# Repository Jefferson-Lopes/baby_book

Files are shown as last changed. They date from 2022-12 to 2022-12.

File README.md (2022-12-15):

# Baby Engineer: Logic Gates

The book "Baby Engineer: Logic Gates" is designed to teach logic gates to kids and teenagers. It is especially appealing to kids with autism since it uses visual and auditory signs to keep their interest.

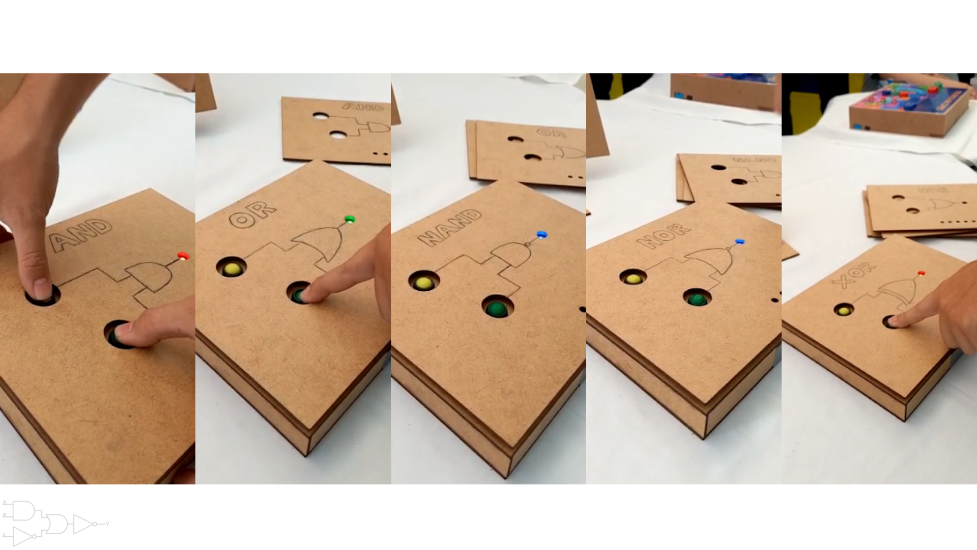
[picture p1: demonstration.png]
demo


# Development

## Circuit

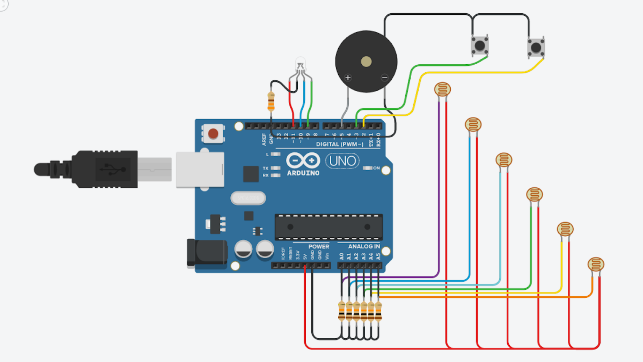
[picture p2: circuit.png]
circuit


## 3D design

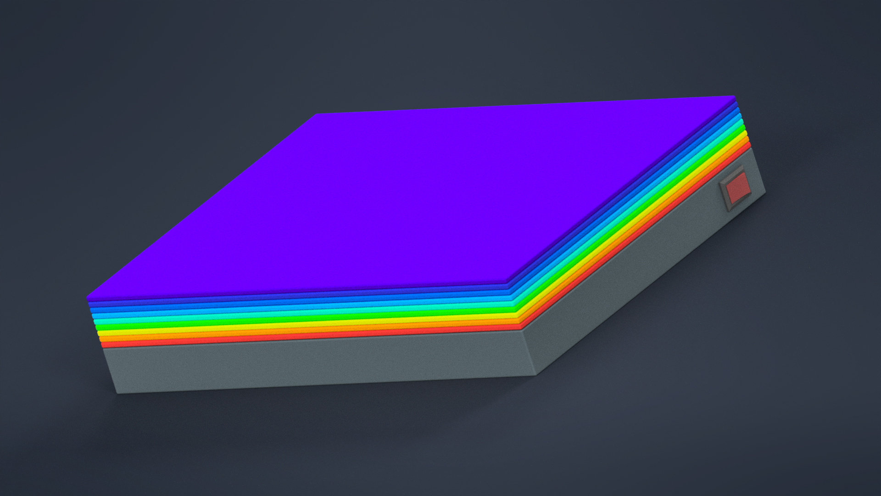
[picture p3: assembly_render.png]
render

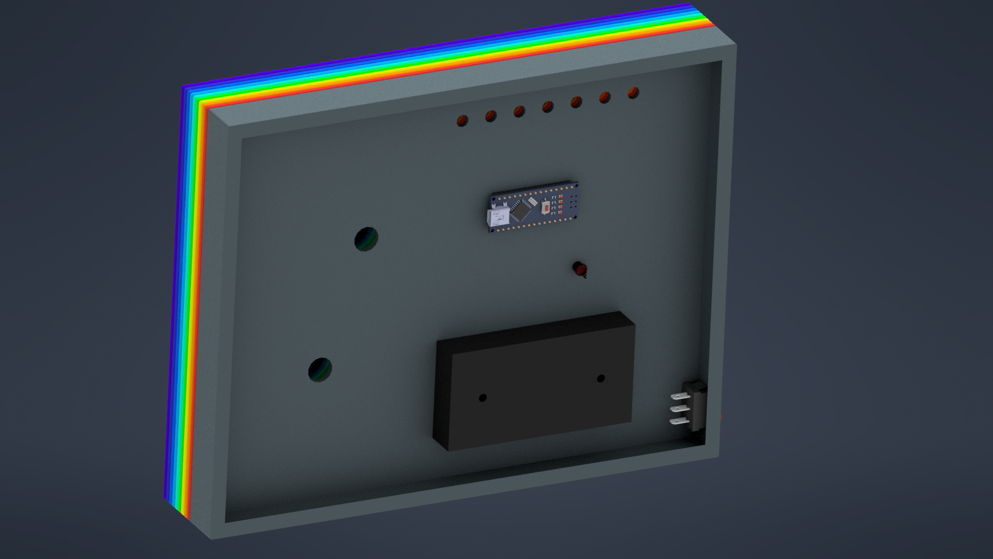
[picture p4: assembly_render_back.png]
render back


## Laser cut

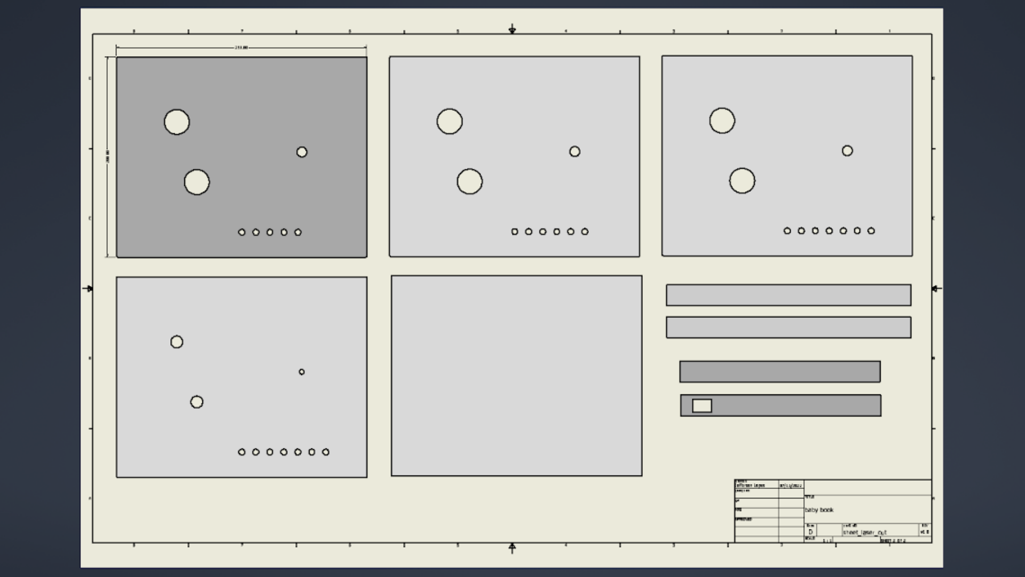
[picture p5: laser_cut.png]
laser cut


# Delivery day

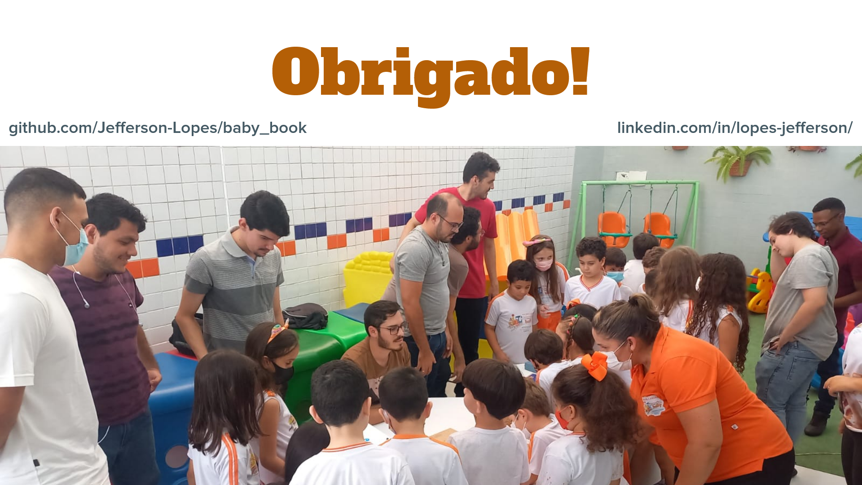
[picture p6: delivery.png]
delivery day


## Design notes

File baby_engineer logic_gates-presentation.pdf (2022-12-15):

# baby engineer:

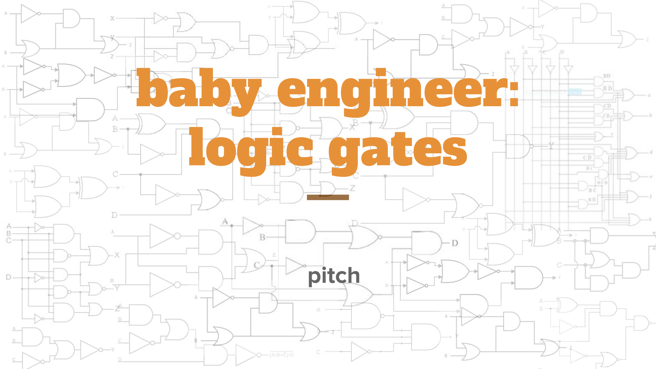
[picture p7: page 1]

# logic gates

# pitch

# Resolução de problemas

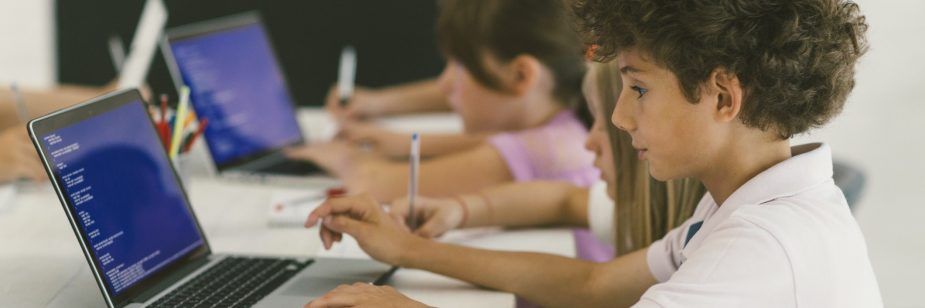
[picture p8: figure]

# Soluções existentes e limitações

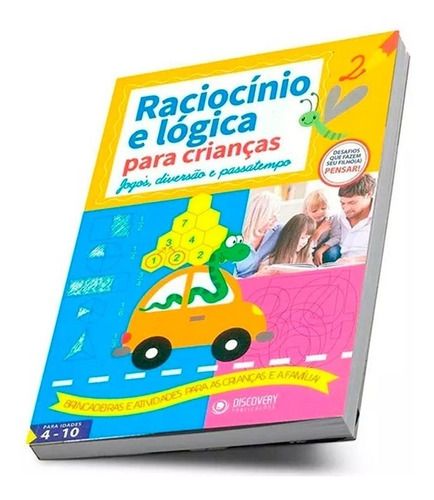
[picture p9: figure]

### - sem inovação de ensino

### - falta de técnicas de inclusão

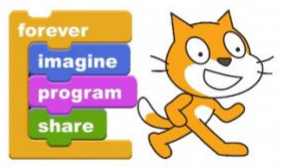
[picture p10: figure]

### - falta de experiência imersiva com tato

### - maior custo para implementação em escolas

# Solução proposta

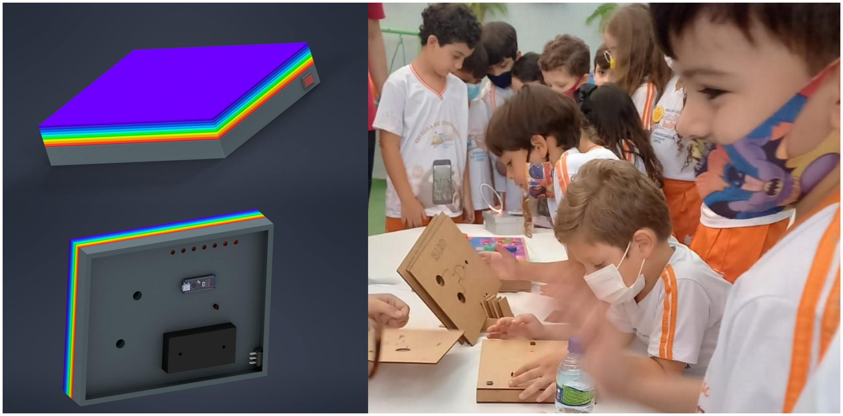
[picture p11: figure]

# Diferencial

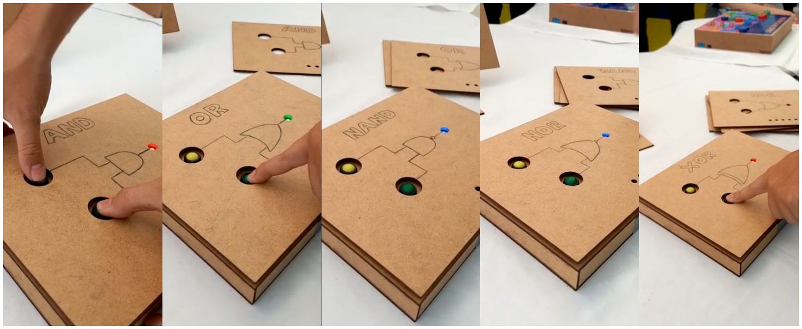
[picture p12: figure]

# Público alvo

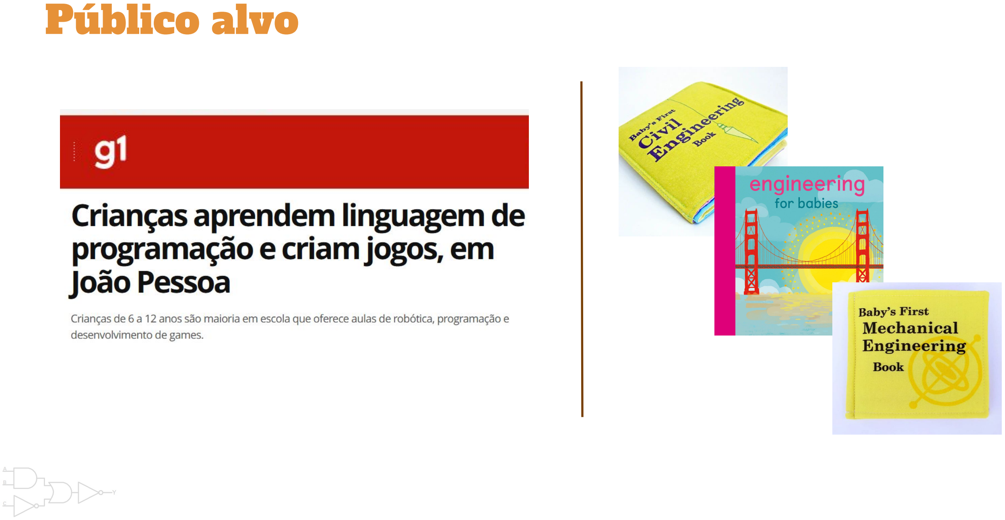
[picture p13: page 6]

# Custos

custo de desenvolvimento

descrição | quant. | valor unitário | custo
MDF / corte a laser | 1 | R$ 80,00 | R$ 80,00
Arduino Uno | 1 | R$ 60,00 | R$ 60,00
Suporte para pilhas | 1 | R$ 7,50 | R$ 7,50
Buzzer | 1 | R$ 2,50 | R$ 2,50
chave on off | 1 | R$ 2,50 | R$ 2,50
push button | 2 | R$ 4,90 | R$ 9,80
fios | 2 | R$ 1,90 | R$ 3,80
LDR | 7 | R$ 0,50 | R$ 3,50
tempo de desenvolvimento | 20 | R$ 15,00 | R$ 300,00
custo total de desenvolvimento | R$ 469,60

custo de produção

descrição | quant. | valor unitário | custo
MDF / corte a laser | 1 | R$ 50,00 | R$ 50,00
MCU Atmega328p | 1 | R$ 15,00 | R$ 15,00
PCB na JLCPCB | 1 | R$ 5,00 | R$ 5,00
bateria 9V | 1 | R$ 12,00 | R$ 12,00
conector jack bateria | 1 | R$ 2,50 | R$ 2,50
LED RGB difuso | 1 | R$ 0,50 | R$ 0,50
Buzzer | 1 | R$ 2,50 | R$ 2,50
LDR | 7 | R$ 0,50 | R$ 3,50
botão fliperama | 2 | R$ 10,00 | R$ 20,00
chave on off | 1 | R$ 2,50 | R$ 2,50
tempo de montagem | 4 | R$ 15,00 | R$ 60,00
custo total por unidade | R$ 173,50

# ROI (retorno sobre investimento)

venda à R$250,00

quant. | custo | entrada | balanço
0 | R$ 469,60 | R$ 0,00 | -R$ 469,60
1 | R$ 643,10 | R$ 250,00 | -R$ 393,10
2 | R$ 816,60 | R$ 500,00 | -R$ 316,60
3 | R$ 990,10 | R$ 750,00 | -R$ 240,10
4 | R$ 1.163,60 | R$ 1.000,00 | -R$ 163,60
5 | R$ 1.337,10 | R$ 1.250,00 | -R$ 87,10
6 | R$ 1.510,60 | R$ 1.500,00 | -R$ 10,60
7 | R$ 1.684,10 | R$ 1.750,00 | R$ 65,90
8 | R$ 1.857,60 | R$ 2.000,00 | R$ 142,40
9 | R$ 2.031,10 | R$ 2.250,00 | R$ 218,90
10 | R$ 2.204,60 | R$ 2.500,00 | R$ 295,40

venda à R$300,00

quant. | custo | entrada | balanço
0 | R$ 469,60 | R$ 0,00 | -R$ 469,60
1 | R$ 643,10 | R$ 300,00 | -R$ 343,10
2 | R$ 816,60 | R$ 600,00 | -R$ 216,60
3 | R$ 990,10 | R$ 900,00 | -R$ 90,10
4 | R$ 1.163,60 | R$ 1.200,00 | R$ 36,40
5 | R$ 1.337,10 | R$ 1.500,00 | R$ 162,90
6 | R$ 1.510,60 | R$ 1.800,00 | R$ 289,40
7 | R$ 1.684,10 | R$ 2.100,00 | R$ 415,90
8 | R$ 1.857,60 | R$ 2.400,00 | R$ 542,40
9 | R$ 2.031,10 | R$ 2.700,00 | R$ 668,90
10 | R$ 2.204,60 | R$ 3.000,00 | R$ 795,40

# ROI (retorno sobre investimento)

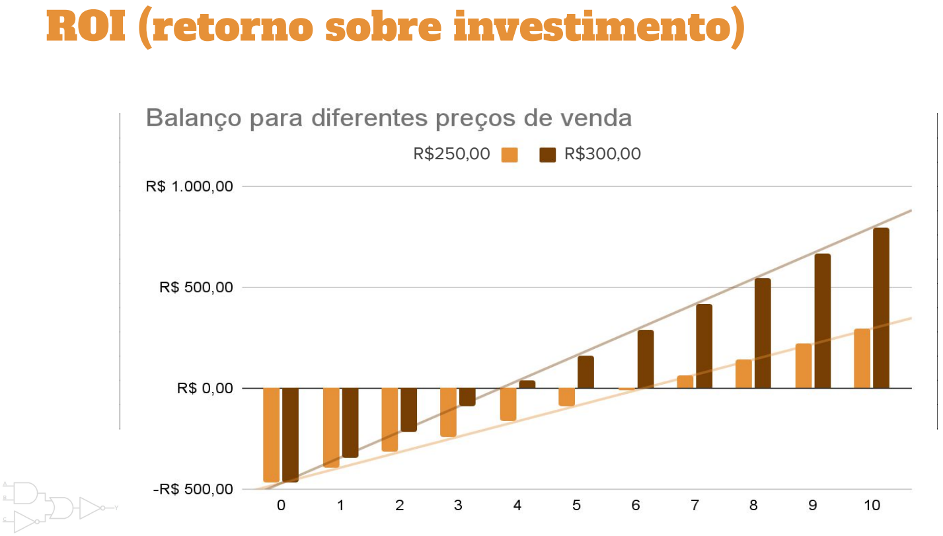
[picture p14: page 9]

venda à R$250,00

quant. | custo | entrada | balanço
0 | R$ 469,60 | R$ 0,00 | -R$ 469,60
1 | R$ 643,10 | R$ 250,00 | -R$ 393,10
2 | R$ 816,60 | R$ 500,00 | -R$ 316,60
3 | R$ 990,10 | R$ 750,00 | -R$ 240,10
4 | R$ 1.163,60 | R$ 1.000,00 | -R$ 163,60
5 | R$ 1.337,10 | R$ 1.250,00 | -R$ 87,10
6 | R$ 1.510,60 | R$ 1.500,00 | -R$ 10,60
7 | R$ 1.684,10 | R$ 1.750,00 | R$ 65,90
8 | R$ 1.857,60 | R$ 2.000,00 | R$ 142,40
9 | R$ 2.031,10 | R$ 2.250,00 | R$ 218,90
10 | R$ 2.204,60 | R$ 2.500,00 | R$ 295,40

venda à R$300,00

quant. | custo | entrada | balanço
0 | R$ 469,60 | R$ 0,00 | -R$ 469,60
1 | R$ 643,10 | R$ 300,00 | -R$ 343,10
2 | R$ 816,60 | R$ 600,00 | -R$ 216,60
3 | R$ 990,10 | R$ 900,00 | -R$ 90,10
4 | R$ 1.163,60 | R$ 1.200,00 | R$ 36,40
5 | R$ 1.337,10 | R$ 1.500,00 | R$ 162,90
6 | R$ 1.510,60 | R$ 1.800,00 | R$ 289,40
7 | R$ 1.684,10 | R$ 2.100,00 | R$ 415,90
8 | R$ 1.857,60 | R$ 2.400,00 | R$ 542,40
9 | R$ 2.031,10 | R$ 2.700,00 | R$ 668,90
10 | R$ 2.204,60 | R$ 3.000,00 | R$ 795,40
R$250,00 | R$300,00

# Obrigado!

github.com/Jefferson-Lopes/baby_book | linkedin.com/in/lopes-jefferson/

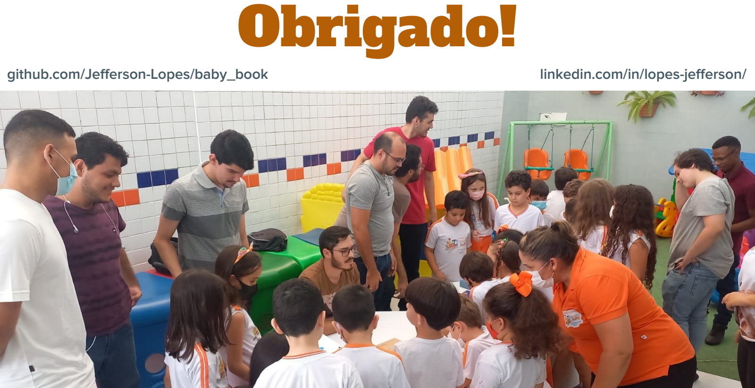
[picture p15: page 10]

# baby engineer:

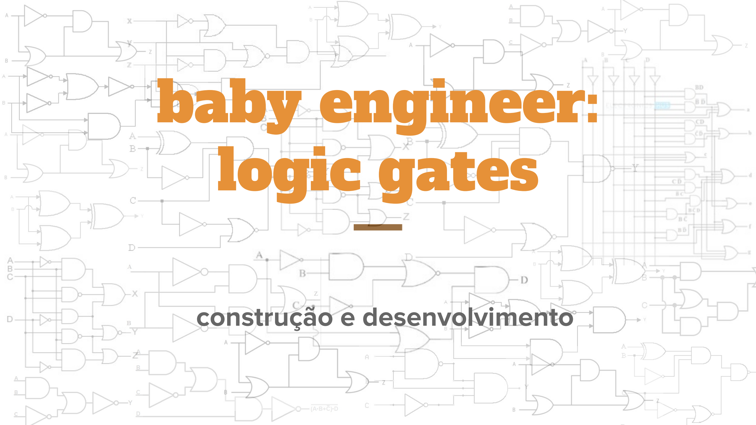
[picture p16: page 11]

# logic gates

# construção e desenvolvimento

# Layout do brinquedo

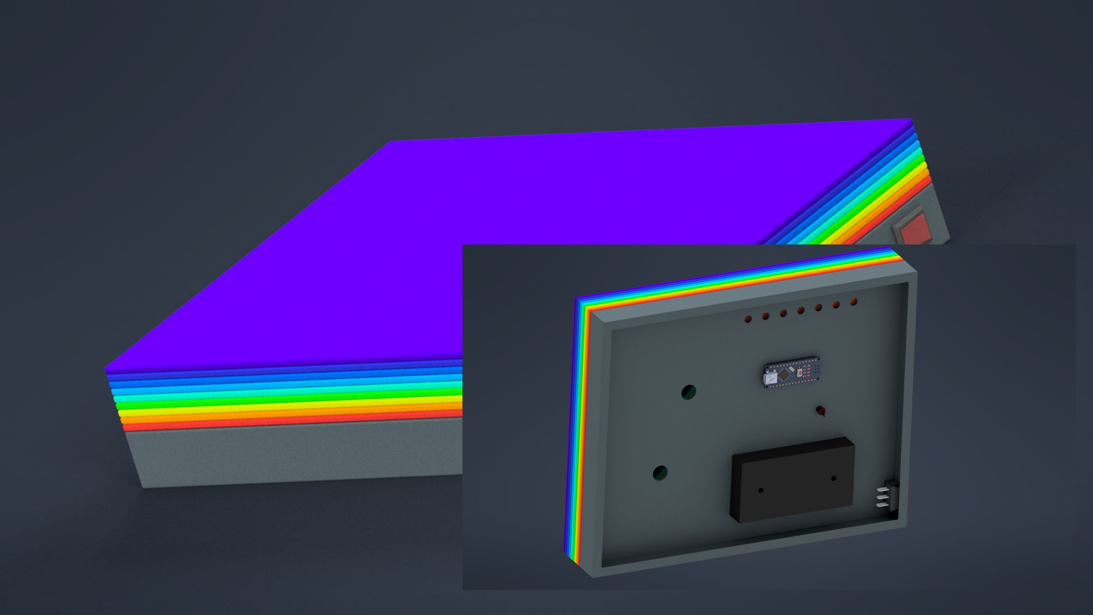
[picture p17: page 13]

# Construção em MDF / corte a laser

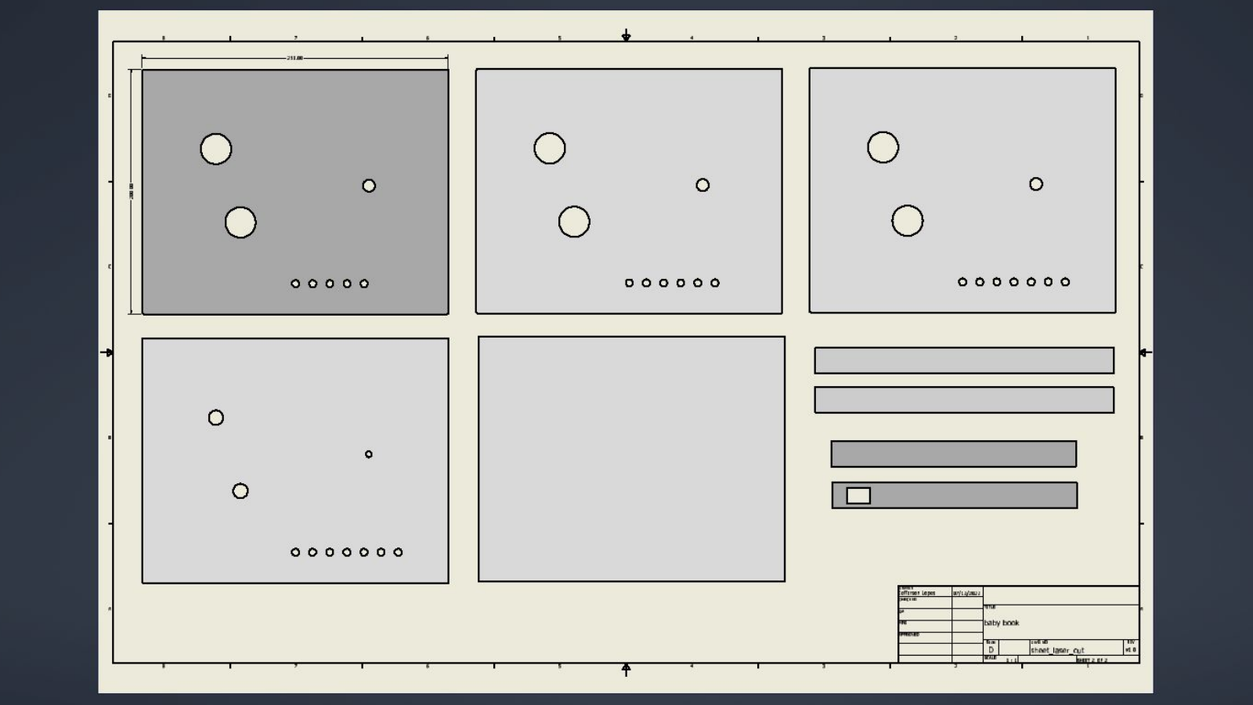
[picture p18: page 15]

# Circuito

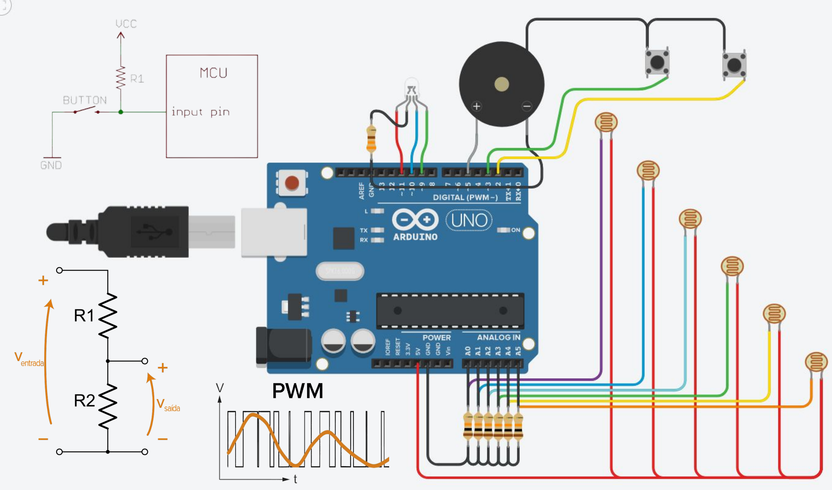
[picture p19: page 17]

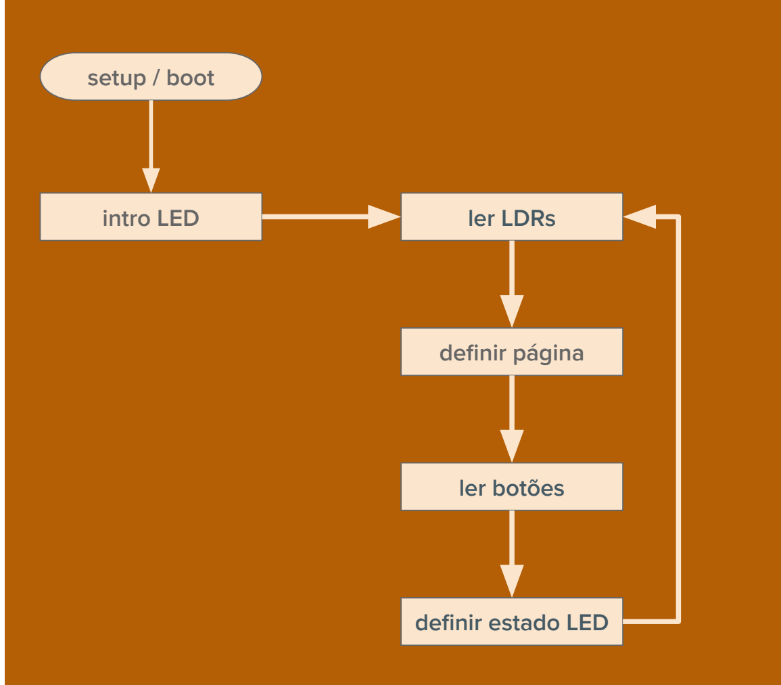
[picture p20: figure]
setup / boot; intro LED; ler LDRs; definir página; ler botões; definir estado LED

# Código

# Diagrama de blocos

# Funcionamento

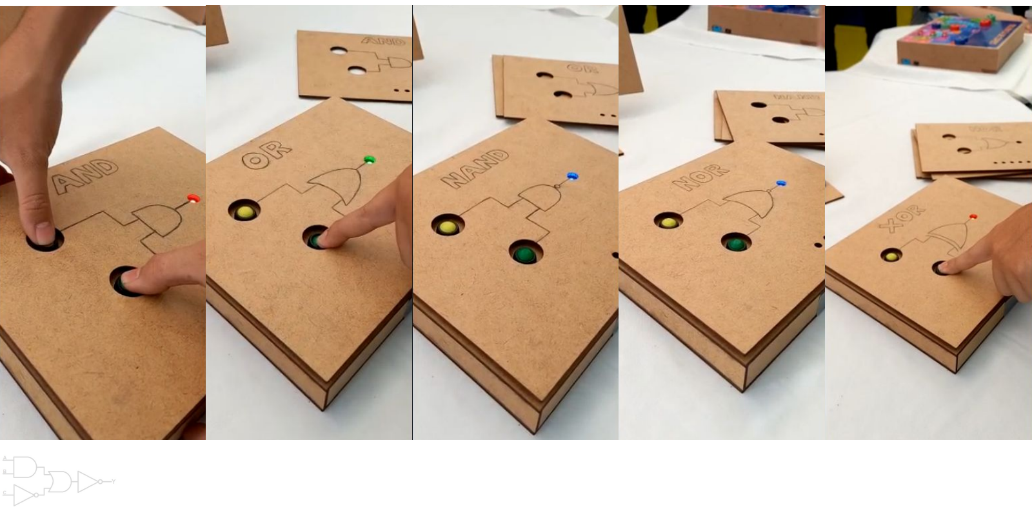
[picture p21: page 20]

# Obrigado!

github.com/Jefferson-Lopes/baby_book | linkedin.com/in/lopes-jefferson/

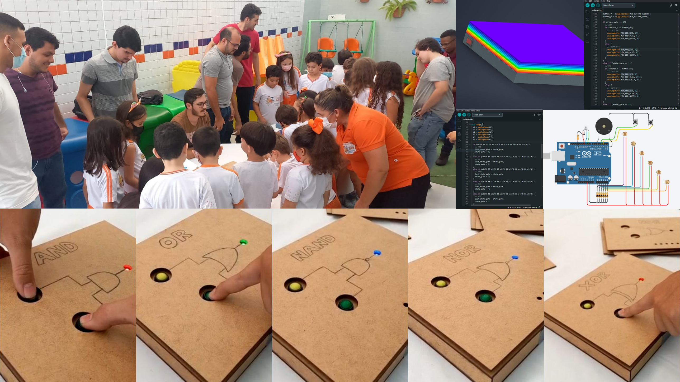
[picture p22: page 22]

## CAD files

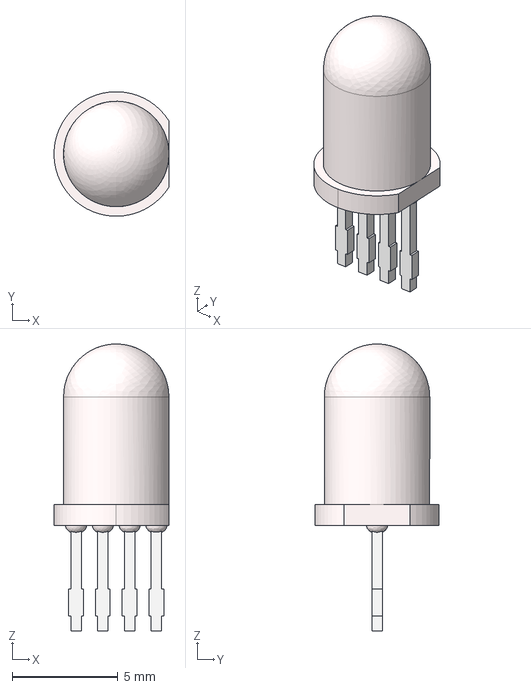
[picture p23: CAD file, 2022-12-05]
CAD/imported/LED T-1, dia 5mm, RGB, h2mm.stp
5.45 x 5.90 x 13.6 mm

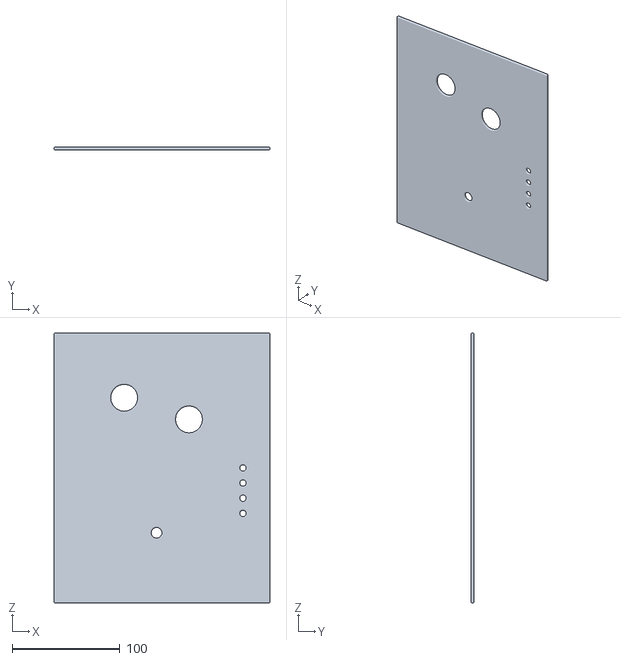
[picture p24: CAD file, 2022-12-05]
CAD/impressão/pages_05_nand.stl
200.0 x 3.00 x 250.0

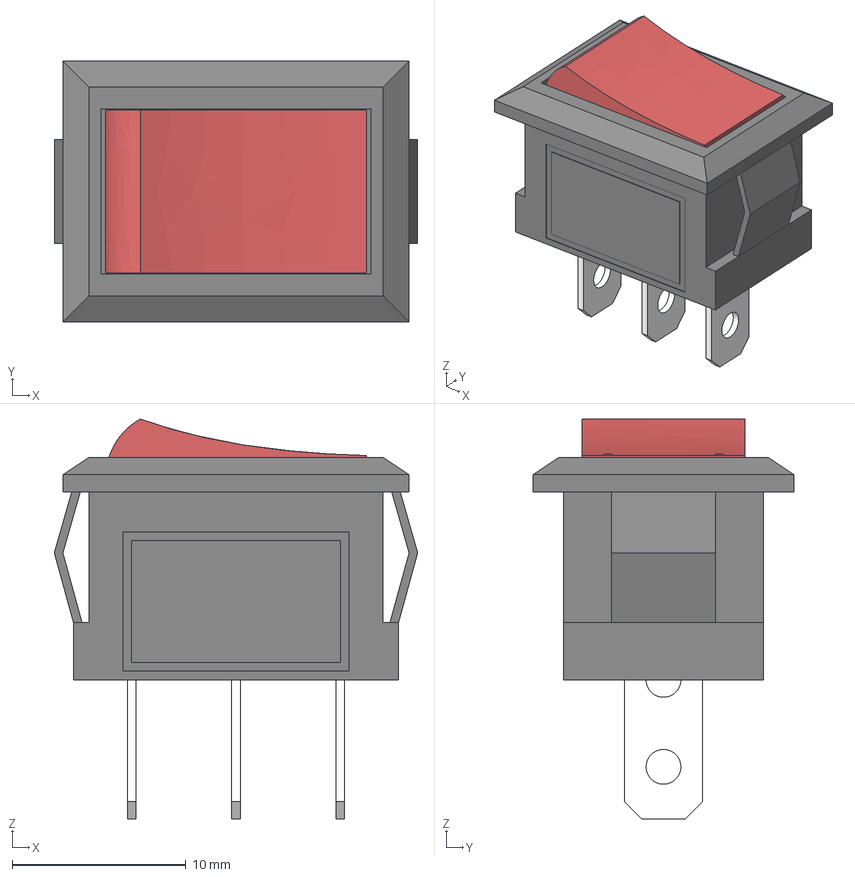
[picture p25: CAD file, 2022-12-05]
CAD/imported/pwr_switch.step
20.9 x 15.0 x 23.0 mm

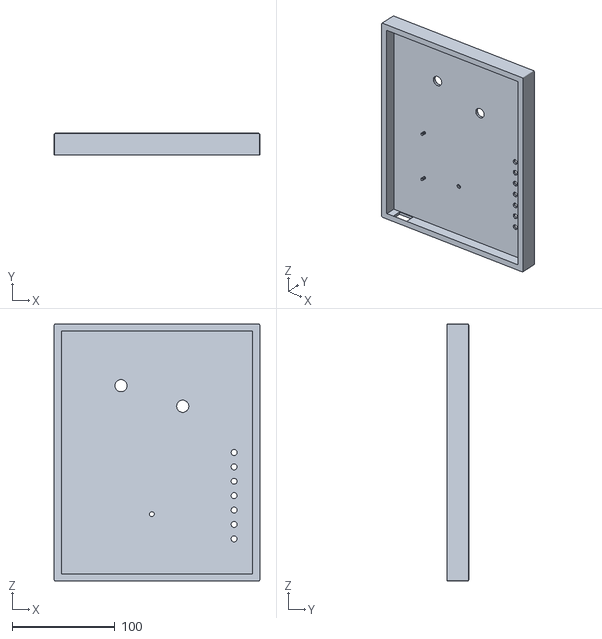
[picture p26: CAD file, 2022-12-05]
CAD/impressão/back.stl
200.0 x 21.0 x 250.0

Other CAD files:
CAD/drawings/laser_cut_Sheet_1.dxf
CAD/drawings/laser_cut.dwg
CAD/impressão/pages_03_and.stl
CAD/drawings/laser_cut_Sheet_2.dxf
CAD/impressão/pages_02_not.stl
CAD/impressão/pages_07_xor.stl
CAD/impressão/back_cover.stl
CAD/impressão/pages_06_nor.stl
CAD/impressão/pages_08_extra.stl
CAD/impressão/pages_00_cover.stl
CAD/impressão/pages_04_or.stl
CAD/impressão/pages_01_wire.stl
CAD/back.ipt
CAD/back_cover.ipt
CAD/back_side_botton.ipt
CAD/back_side_left.ipt
CAD/back_side_right.ipt
CAD/back_side_top.ipt
CAD/back_top.ipt
CAD/battery_case.ipt
CAD/lines_base.ipt
CAD/pages_00_cover.ipt
CAD/pages_01_wire.ipt
CAD/pages_02_not.ipt
CAD/pages_03_and.ipt
CAD/pages_04_or.ipt
CAD/pages_05_nand.ipt
CAD/pages_06_nor.ipt
CAD/pages_07_xor.ipt
CAD/pages_08_extra.ipt

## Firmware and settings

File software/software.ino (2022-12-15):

/**
 * @file software.ino
 * @author Jefferson Lopes (jefferson.lopes@ee.ufcg.edu.br)
 * @brief the book "Baby Engineer: Logic Gates" is designed to teach logic gates 
 *        to kids and teenagers. It is especially appealing to kids with autism 
 *        since it uses visual and auditory signs to keep their interest.
 * @version 0.1
 * @date 2022-12-15
 * 
 * @copyright Copyright (c) 2022
 * 
 */

// pinout
#define PIN_PIEZO 3
#define PIN_LED_RED 11
#define PIN_LED_BLUE 10
#define PIN_LED_GREEN 9
#define PIN_BUTTON_GREEN 4
#define PIN_BUTTON_YELLOW 2

// configs
#define TH 100 // THRESHOLD
#define INTRO_TIME 500 // intro delay time

// states
typedef enum {
    INIT,
    AND,
    OR,
    NAND,
    NOR,
    XOR,
    LATCH
} state_t;

// global vars
bool button_Y, button_G;
state_t state_gate = INIT;
state_t last_state_gate = INIT;
uint16_t a0, a1, a2, a3, a4, a5;

void setup(){
    pinMode(PIN_PIEZO, OUTPUT);
    pinMode(PIN_LED_RED, OUTPUT);
    pinMode(PIN_LED_BLUE, OUTPUT);
    pinMode(PIN_LED_GREEN, OUTPUT);
    pinMode(PIN_BUTTON_GREEN, INPUT_PULLUP);
    pinMode(PIN_BUTTON_YELLOW, INPUT_PULLUP);

    // init and config serial monitor
    Serial.begin(9600);

    // initial beep
    analogWrite(PIN_PIEZO, 125); delay(100);
    analogWrite(PIN_PIEZO, 0);   delay(100);
    analogWrite(PIN_PIEZO, 125); delay(100);
    analogWrite(PIN_PIEZO, 0);

    // RGB intro
    analogWrite(PIN_LED_RED, 255); delay(INTRO_TIME);
    analogWrite(PIN_LED_BLUE, 255); delay(INTRO_TIME);
    analogWrite(PIN_LED_GREEN, 255); delay(INTRO_TIME);
    analogWrite(PIN_LED_RED, 0); delay(INTRO_TIME);
    analogWrite(PIN_LED_BLUE, 0); delay(INTRO_TIME);
    analogWrite(PIN_LED_GREEN, 0); delay(INTRO_TIME);
}

void loop(){
    define_state();

    update_logic();

    delay(10);
}

void define_state(void){
    a0 = analogRead(A0);
    a1 = analogRead(A1);
    a2 = analogRead(A2);
    a3 = analogRead(A3);
    a4 = analogRead(A4);
    a5 = analogRead(A5);

    if (a0 > TH && a1 < TH && a2 < TH && a3 < TH && a4 < TH && a5 < TH){
        // AND
        last_state_gate = state_gate;
        state_gate = AND;
    }
    else if (a0 > TH && a1 > TH && a2 < TH && a3 < TH && a4 < TH && a5 < TH){
        // OR
        last_state_gate = state_gate;
        state_gate = OR;
    }
    else if (a0 > TH && a1 > TH && a2 > TH && a3 < TH && a4 < TH && a5 < TH){
        // NAND
        last_state_gate = state_gate;
        state_gate = NAND;
    }
    else if (a0 > TH && a1 > TH && a2 > TH && a3 > TH && a4 < TH && a5 < TH){
        // NOR
        last_state_gate = state_gate;
        state_gate = NOR;
    }
    else if (a0 > TH && a1 > TH && a2 > TH && a3 > TH && a4 > TH && a5 < TH){
        // XOR
        last_state_gate = state_gate;
        state_gate = XOR;
    }
    else if (a0 > TH && a1 > TH && a2 > TH && a3 > TH && a4 > TH && a5 > TH){
        // LATCH
        last_state_gate = state_gate;
        state_gate = LATCH;
    }

    if (last_state_gate != state_gate){
        // turn off LED
        analogWrite(PIN_LED_RED, 0);
        analogWrite(PIN_LED_BLUE, 0);
        analogWrite(PIN_LED_GREEN, 0);

        // debug message
        Serial.print("New state: ");
        Serial.println(state_gate);

        delay(10);
    }
}

void update_logic(){
    button_Y = !digitalRead(PIN_BUTTON_YELLOW); // inverted logic
    button_G = !digitalRead(PIN_BUTTON_GREEN);  // inverted logic

    if (state_gate == AND){
        // AND
        if (button_Y & button_G){
            // turn on
            analogWrite(PIN_LED_RED, 255);
            analogWrite(PIN_LED_BLUE, 0);
            analogWrite(PIN_LED_GREEN, 0);
        }
        else{
            // turn off
            analogWrite(PIN_LED_RED, 0);
            analogWrite(PIN_LED_BLUE, 0);
            analogWrite(PIN_LED_GREEN, 0);
        }
    }
    else if (state_gate == OR){
        // OR
        if (button_Y | button_G){
            // turn on
            analogWrite(PIN_LED_RED, 0);
            analogWrite(PIN_LED_BLUE, 255);
            analogWrite(PIN_LED_GREEN, 0);
        }
        else{
            // turn off
            analogWrite(PIN_LED_RED, 0);
            analogWrite(PIN_LED_BLUE, 0);
            analogWrite(PIN_LED_GREEN, 0);
        }
    }
    else if (state_gate == NAND){
        // NAND
        if (!(button_Y & button_G)){
            // turn on
            analogWrite(PIN_LED_RED, 255);
            analogWrite(PIN_LED_BLUE, 255);
            analogWrite(PIN_LED_GREEN, 0);
        }
        else{
            // turn off
            analogWrite(PIN_LED_RED, 0);
            analogWrite(PIN_LED_BLUE, 0);
            analogWrite(PIN_LED_GREEN, 0);
        }
    }
    else if (state_gate == NOR){
        // NOR
        if (!(button_Y | button_G)){
            // turn on
            analogWrite(PIN_LED_RED, 0);
            analogWrite(PIN_LED_BLUE, 0);
            analogWrite(PIN_LED_GREEN, 255);
        }
        else{
            // turn off
            analogWrite(PIN_LED_RED, 0);
            analogWrite(PIN_LED_BLUE, 0);
            analogWrite(PIN_LED_GREEN, 0);
        }
    }
    else if (state_gate == XOR){
        // XOR
        if (button_Y ^ button_G){
            // turn on
            analogWrite(PIN_LED_RED, 255);
            analogWrite(PIN_LED_BLUE, 0);
            analogWrite(PIN_LED_GREEN, 255);
        }
        else{
            // turn off
            analogWrite(PIN_LED_RED, 0);
            analogWrite(PIN_LED_BLUE, 0);
            analogWrite(PIN_LED_GREEN, 0);
        }
    }
    else if (state_gate == LATCH){
        // LATCH
        if (button_Y && !button_G){
            // set
            // turn on
            analogWrite(PIN_LED_RED, 255);
            analogWrite(PIN_LED_BLUE, 255);
            analogWrite(PIN_LED_GREEN, 255);
        }
        else if (!button_Y && button_G){
            // reset
            // turn off
            analogWrite(PIN_LED_RED, 0);
            analogWrite(PIN_LED_BLUE, 0);
            analogWrite(PIN_LED_GREEN, 0);
        }
    }
}

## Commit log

2022-12-05 create CAD v1
    [LED T-1, dia 5mm, RGB, h2mm.stp, back.ipt, back.stl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]
2022-12-07 move imported parts
    [LED T-1, dia 5mm, RGB, h2mm.stp, pwr_switch.step]
2022-12-07 adapt to laser cutting
    [back.ipt, back_cover.ipt, back_side_botton.ipt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]
2022-12-07 create drawings
    [laser_cut.dwg, laser_cut_Sheet_1.dxf, laser_cut_Sheet_2.dxf]
